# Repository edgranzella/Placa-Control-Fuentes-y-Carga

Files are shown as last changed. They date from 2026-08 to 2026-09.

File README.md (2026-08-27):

# Placa Control Fuentes y Carga - Hardware y PCB 🚀

Este repositorio contiene el diseño completo de la placa de circuito impreso (PCB) desarrollado en **KiCad 10** para el sistema de **Control de Fuentes y Gestión de Carga de Baterías**.

---

## 📌 Características del Diseño
* **Gestión de Energía:** Monitoreo y conmutación inteligente entre fuentes de alimentación principales y sistemas de respaldo por batería.
* **Etapa de Carga Integrada:** Circuito de control dedicado para la recarga segura, regulación de corriente y protección térmica del banco de baterías.
* **Supervisión Analógica:** Divisores de tensión de precisión y sensores de corriente dispuestos para la telemetría de voltajes críticos.
* **Protección de Entrada:** Fusibles rearmables, diodos de protección contra inversión de polaridad y supresores de transitorios (TVS).

---

## 🛠️ Especificaciones Técnicas de Fabricación
Configuración sugerida basada en las reglas de diseño (DRC) aplicadas en KiCad 10:

| Parámetro | Configuración Sugerida |
| :--- | :--- |
| **Capas (Layers)** | 2 Capas |
| **Grosor de la Placa** | 1.6 mm |
| **Grosor del Cobre** | 1 oz / 2 oz (Recomendado para pistas de alta corriente en etapas de carga) |
| **Acabado Superficial** | HASL (with lead) o ENIG |

---

## 👥 Desarrollado por
* **Damian Granzella** - *Ingeniería de Hardware* - [edgranzella](https://github.com)

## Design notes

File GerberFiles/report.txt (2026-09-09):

Trazado a 'C:\Users\dgranzella\Documents\Control de Fuentes y Batería\Placa Control Fuentes y Carga\GerberFiles\Placa Control Fuentes y Carga-F_Cu.gbr'.
Trazado a 'C:\Users\dgranzella\Documents\Control de Fuentes y Batería\Placa Control Fuentes y Carga\GerberFiles\Placa Control Fuentes y Carga-B_Cu.gbr'.
Trazado a 'C:\Users\dgranzella\Documents\Control de Fuentes y Batería\Placa Control Fuentes y Carga\GerberFiles\Placa Control Fuentes y Carga-F_Paste.gbr'.
Trazado a 'C:\Users\dgranzella\Documents\Control de Fuentes y Batería\Placa Control Fuentes y Carga\GerberFiles\Placa Control Fuentes y Carga-F_Silkscreen.gbr'.
Trazado a 'C:\Users\dgranzella\Documents\Control de Fuentes y Batería\Placa Control Fuentes y Carga\GerberFiles\Placa Control Fuentes y Carga-F_Mask.gbr'.
Trazado a 'C:\Users\dgranzella\Documents\Control de Fuentes y Batería\Placa Control Fuentes y Carga\GerberFiles\Placa Control Fuentes y Carga-B_Mask.gbr'.
Trazado a 'C:\Users\dgranzella\Documents\Control de Fuentes y Batería\Placa Control Fuentes y Carga\GerberFiles\Placa Control Fuentes y Carga-Edge_Cuts.gbr'.
Trazado a 'C:\Users\dgranzella\Documents\Control de Fuentes y Batería\Placa Control Fuentes y Carga\GerberFiles\Placa Control Fuentes y Carga-F_Courtyard.gbr'.
Trazado a 'C:\Users\dgranzella\Documents\Control de Fuentes y Batería\Placa Control Fuentes y Carga\GerberFiles\Placa Control Fuentes y Carga-F_Fab.gbr'.
Archivo de trabajo Gerber 'C:\Users\dgranzella\Documents\Control de Fuentes y Batería\Placa Control Fuentes y Carga\GerberFiles\Placa Control Fuentes y Carga-job.gbrjob' creado.
Info: Listo.

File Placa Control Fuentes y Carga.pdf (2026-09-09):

Referencia | Cantidad | Valor | Descripción
C1, C5 | 2 | 1nF/50V | Capacitor cerámico de desacople / filtro
C2 | 1 | 22nF/50V | Capacitor cerámico de desacople
C3, C4, C6, C8, C9, C12, C19, C20, C22, C24, C25 | 11 | 100nF/50V | Capacitor cerámico de desacople común (0.1µF)
C7, C10, C11, C16 | 4 | F102K43Y5RP6UK5R | Capacitor cerámico de alta tensión / dieléctrico Y5R
C13, C14 | 2 | 10uF/25V | Capacitor electrolítico o cerámico de filtrado
C15, C23 | 2 | 470µF/35V low-ESR | Capacitor electrolítico de baja resistencia serie para fuentes conmutadas
C17, C21 | 2 | 10µF/25V | Capacitor electrolítico de filtrado de propósito general
C18 | 1 | 100µF/25V | Capacitor electrolítico de estabilización de tensión
CR1, CR2 | 2 | SMBJ18A | Diodo supresor de picos de tensión (TVS) unidireccional de 18V (SMD)
CR3 | 1 | SMBJ16A | Diodo supresor de picos de tensión (TVS) unidireccional de 16V (SMD)
D1, D4, D6 | 3 | 1N4007 | Diodo rectificador de silicio estándar (1A / 1000V)
D2, D3, D8 | 3 | P2000M | Diodo rectificador de silicio de alta corriente (20A / 1000V)
D5 | 1 | Zener-10V | Diodo Zener de regulación de voltaje fijo (10V)
D7, D9-D11, D16 | 5 | 1N4733A | Diodo Zener de regulación de voltaje de 5.1V / 1W
D12 | 1 | SM712 | Diodo TVS dual asimétrico para protección de líneas de datos (RS-485)
D13, D14 | 2 | SA12CA | Diodo supresor de picos de tensión (TVS) bidireccional de 12V
D15 | 1 | SA6.5CA | Diodo supresor de picos de tensión (TVS) bidireccional de 6.5V
F1 | 1 | ETA 1610-H2-7.5A | Fusible automotriz de acción rápida (tipo mini / disyuntor térmico 7.5A)
F2 | 1 | Polyfuse MF-R500 | Fusible PTC reseteable (Polyswitch) de 5A / protección por sobrecorriente
F3, F4 | 2 | MF-R030 | Fusible PTC reseteable (Polyswitch) de 0.3A (300mA)
F5, F6 | 2 | ETA 1610-H2-5A | Fusible automotriz de acción rápida (tipo mini / disyuntor térmico 5A)
GD1 | 1 | 2036-15-B2LF | Tubo de descarga de gas (GDT) para protección contra sobretensiones (150V)
J1-J9 | 9 | TBP01R1-508-02BE | Bloque de terminales enchufable de 2 pines (Paso 5.08mm)
J10 | 1 | TBP01R1-508-03BE | Bloque de terminales enchufable de 3 pines (Paso 5.08mm)
J11 | 1 | 4P-2.54mm-SHROUDED-VERT | CONN HEADER VERT 4POS 2.54MM SHROUDED THT
JP1-JP4 | 4 | Jumper_2_Open | Puntos de selección mediante Jumper (2 pines, normalmente abiertos)
Q1 | 1 | IRF9540NPbF | Transistor MOSFET de potencia Canal P (-100V, -23A, 117mΩ, 140W, TO-220AB)
Q2 | 1 | 2N3904 | Transistor bipolar BJT de tipo NPN de propósito general / conmutación de baja señal
Q3, Q4 | 2 | BC558 | Transistor bipolar BJT de tipo PNP de bajo ruido y baja señal
Q5 | 1 | IRF5305 | Transistor de potencia MOSFET de Canal P (-55V / -31A)
Q6 | 1 | BC337 | Transistor bipolar BJT de tipo NPN de mediana potencia / corriente (hasta 800mA)
Q7 | 1 | BC327 | Transistor bipolar BJT de tipo PNP de mediana potencia / corriente (hasta 800mA)
R1, R2, R5 | 3 | 150K 1/4W | Resistencia fija de película de carbón/metal de 150 kΩ
R3, R4 | 2 | 56K 0.5W | Resistencia fija de 56 kΩ con disipación de media potencia (0.5 vatios)
R6, R9, R14, R16 | 4 | 10K 1/4W | Resistencia fija de precisión / pull-up estándar de 10 kΩ

Lista de Materiales Placa Controladora de Fuentes y Carga V2

R7 | 1 | 56K 1/4W | Resistencia fija de propósito general de 56 kΩ
R8 | 1 | 3K3 1/4W | Resistencia fija de propósito general de 3.3 kΩ
R10-R12 | 3 | 18K 1/4W | Resistencia fija de propósito general de 18 kΩ
R13, R15 | 2 | 1K 1/4W | Resistencia fija de control / limitación de corriente de 1 kΩ
R17 | 1 | 470 1/4W | Resistencia fija de limitación de corriente de 470 Ω
R18, R19 | 2 | 560 1/4W | Resistencia fija de limitación de corriente de 560 Ω
R20 | 1 | 120 1/4W | Resistencia de terminación de bus de comunicación de 120 Ω
R21, R26 | 2 | 1M 1/4W | Resistencia fija de alta impedancia de 1 MΩ
R22, R23 | 2 | 47 1/4W | Resistencia de amortiguación o protección de baja impedancia de 47 Ω
R24, R25 | 2 | B72214S0271K101 | Varistor de óxido metálico (MOV) de 270V para absorción de transitorios transitorios
RV1-RV3 | 3 | 50K | Potenciómetro / Resistencia variable ajustable de 50 kΩ
TP1-TP12, TP14-TP26 | 25 | TestPoint | Puntos físicos de prueba en el circuito impreso para multímetro/osciloscopio
U1, U6 | 2 | ACS724LLCTR-05AB-T | Sensor de corriente de efecto Hall integrado (aislado, rango ±5A)
U2 | 1 | Relay_Module_WB-083 | Módulo de relé electromecánico para control de cargas de potencia
U3 | 1 | 4N35 | Optoacoplador con salida a fototransistor (aislamiento galvánico de señales)
U4 | 1 | LM2596S_Modulo_Regulable | Módulo regulador de voltaje conmutado Step-Down (reductor DC-DC)
U5 | 1 | Arduino_Nano_ATmega328P | Módulo microcontrolador de desarrollo basado en el chip ATmega328P
U7 | 1 | MAX485E | Circuito integrado transceptor para comunicaciones industriales RS-485 / RS-422
U8 | 1 | MAX22445FAWE+ | Aislador digital galvánico reforzado de alta velocidad y 4 canales
U9 | 1 | RI3-0505S | Convertidor DC-DC aislado de tipo industrial (entrada 5V / salida 5V regulada)

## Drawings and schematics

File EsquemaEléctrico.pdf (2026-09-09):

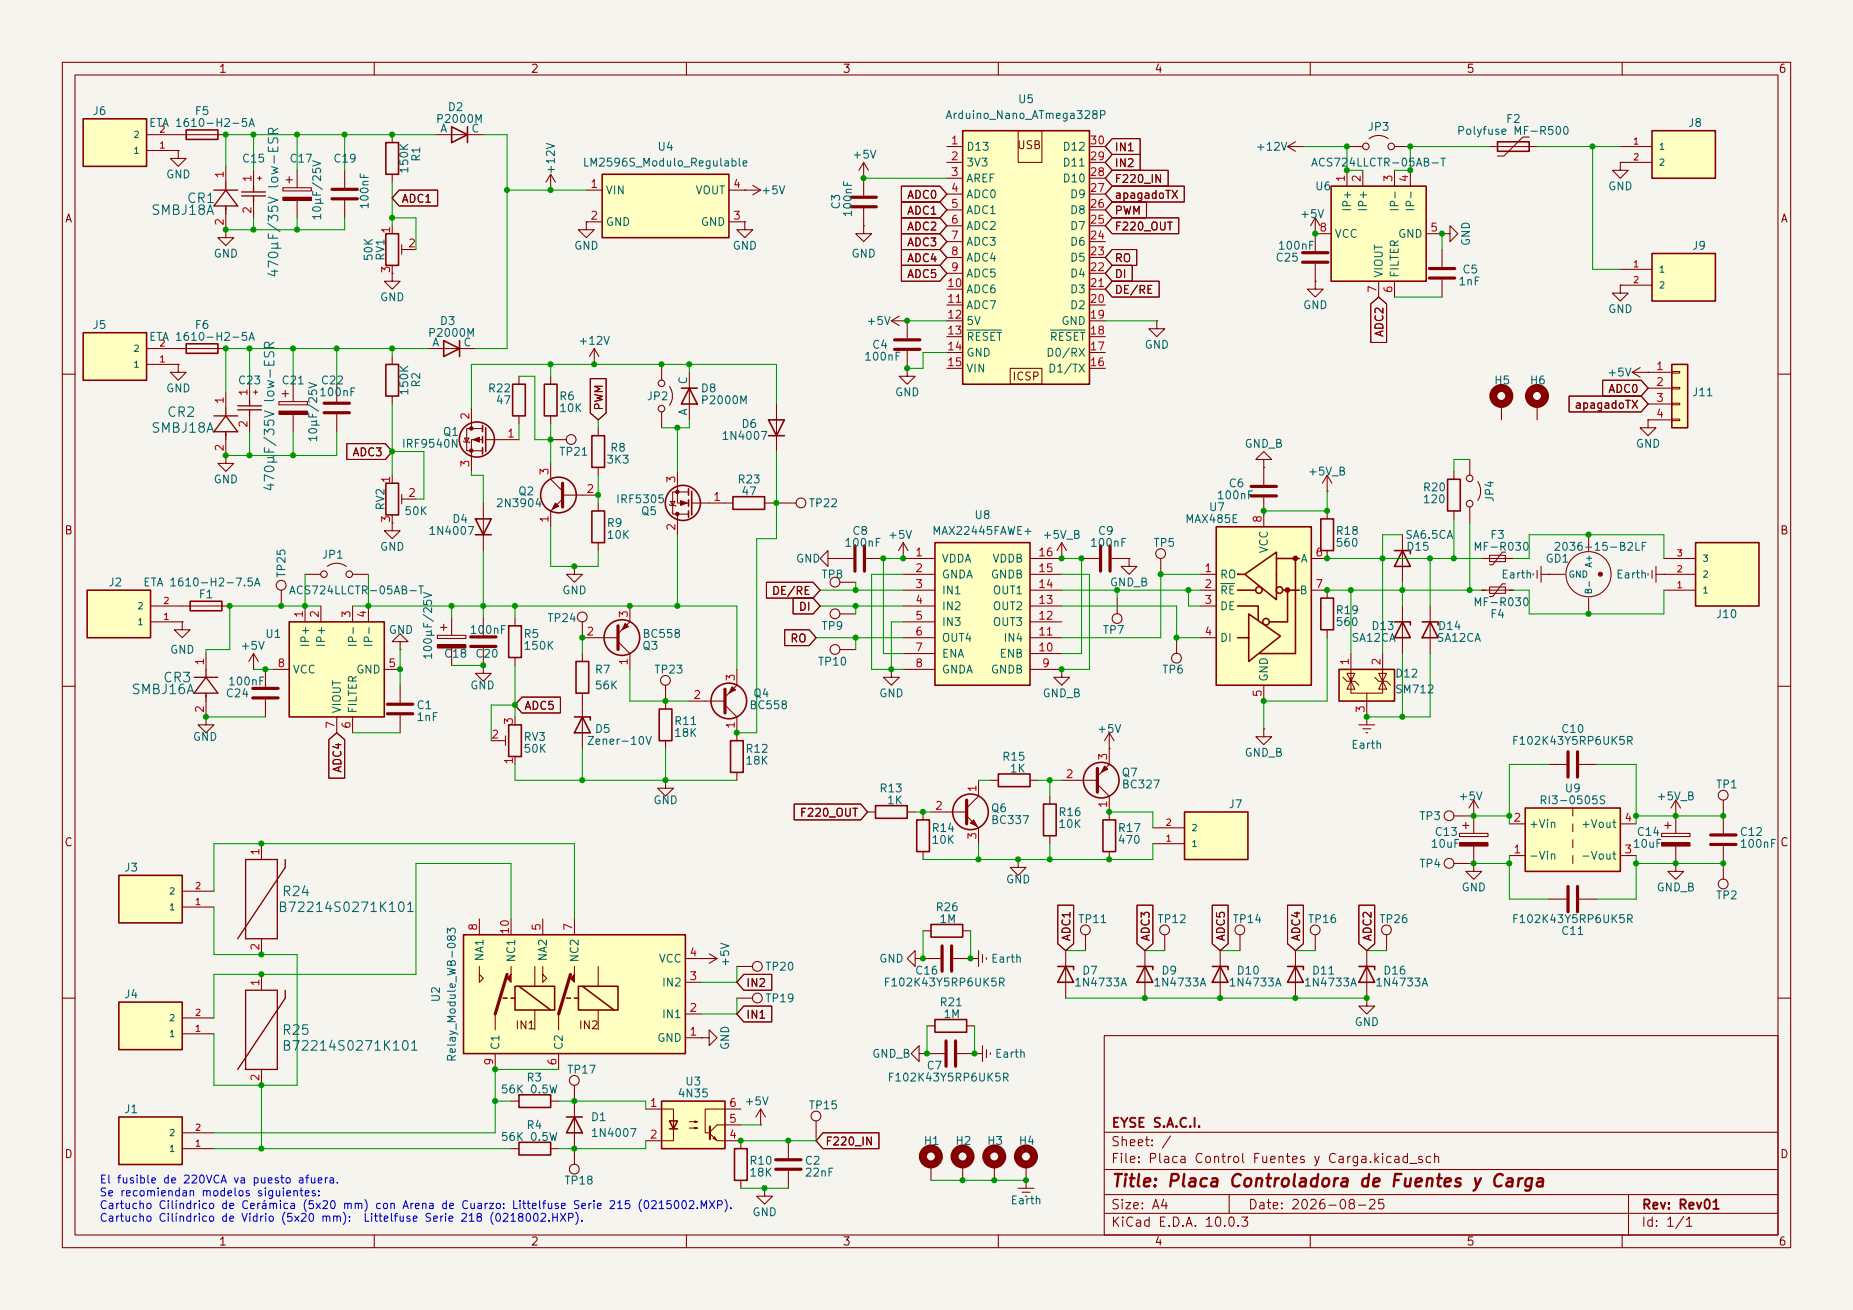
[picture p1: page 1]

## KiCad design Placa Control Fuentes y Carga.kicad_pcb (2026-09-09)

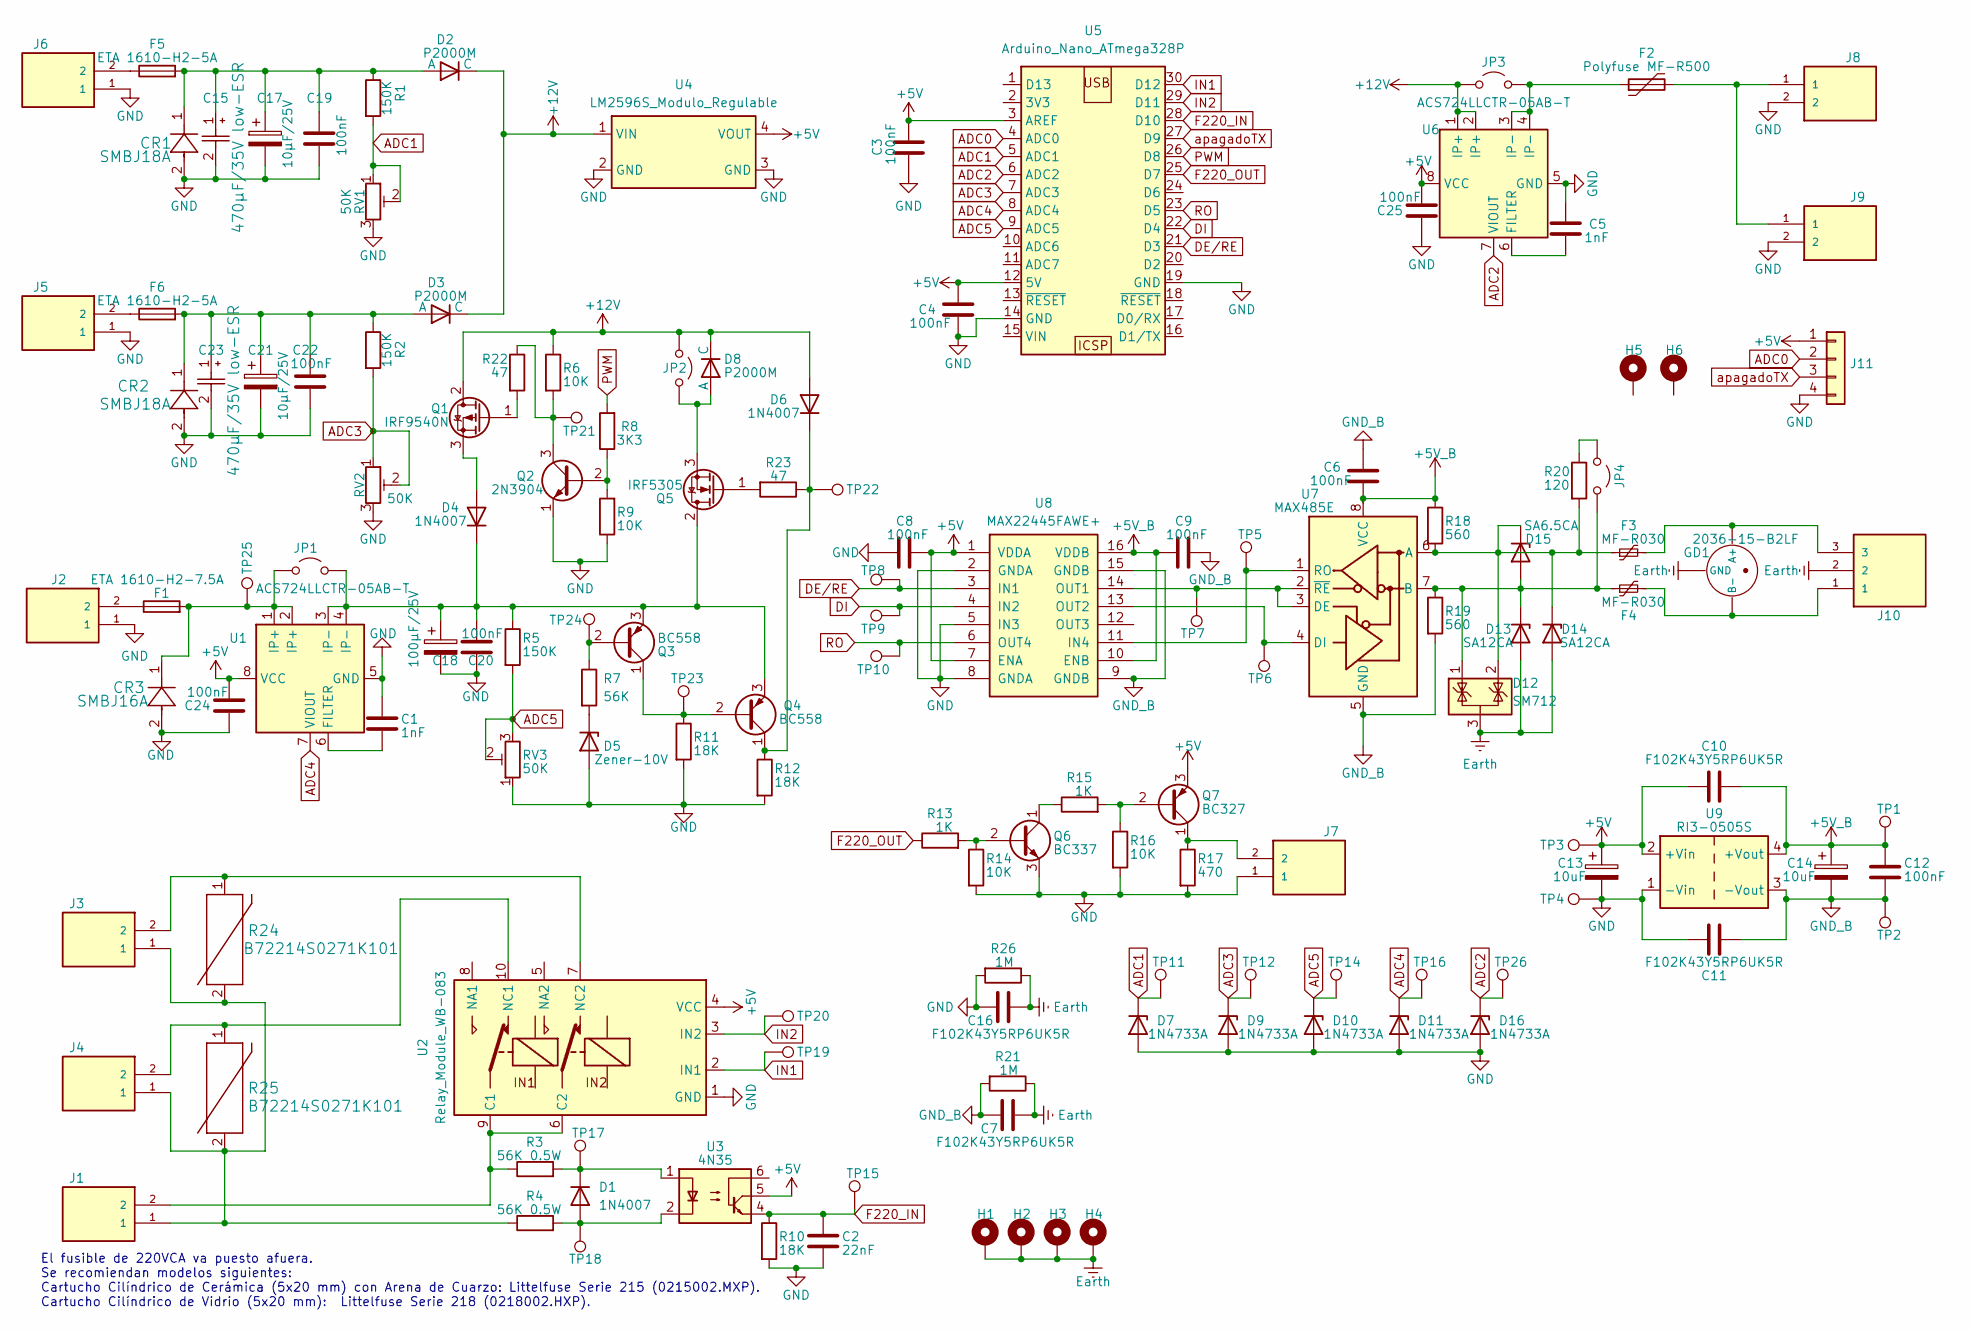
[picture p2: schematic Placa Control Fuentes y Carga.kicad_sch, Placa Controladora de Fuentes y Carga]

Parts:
C1, C5: 1nF; C_Disc_D5.0mm_W2.5mm_P2.50mm
C2: 22nF; C_Disc_D5.0mm_W2.5mm_P2.50mm
C3, C4, C6, C8, C9, C12, C19, C20, C22, C24, C25: 100nF; C_Disc_D5.0mm_W2.5mm_P2.50mm
C7, C10, C11, C16: F102K43Y5RP6UK5R; CAP_F_11X5P_VIS
C13, C14: 10uF; CP_Radial_D5.0mm_P2.00mm
C15, C23: 470µF/35V low-ESR; CAP_UAQ_10X20_NCH
C17, C21: 10µF/25V; CP_Radial_D5.0mm_P2.00mm
C18: 100µF/25V; CP_Radial_D5.0mm_P2.00mm
CR1, CR2: SMBJ18A; DIODE_DO214AA
CR3: SMBJ16A; DIODE_DO214AA
D1, D4, D6: 1N4007; D_DO-41_SOD81_P10.16mm_Horizontal
D2, D3, D8: P2000M; D_P600_R-6_P15.24mm_Horizontal
D5: Zener-10V; D_DO-35_SOD27_P7.62mm_Horizontal
D7, D9, D10, D11, D16: 1N4733A; D_DO-41_SOD81_P10.16mm_Horizontal
D12: SM712; SOT-23_Handsoldering
D13, D14: SA12CA; DO-204AC_SA
D15: SA6.5CA; DO-204AC_SA
F1: ETA 1610-H2-7.5A; FuseHolder_Blade_ATO_Littelfuse_FLR_178.6165
F2: Polyfuse MF-R500; FUSE_MF-R500_BRN
F3, F4: MF-R030; Fuse_Bourns_MF-RHT050
F5, F6: ETA 1610-H2-5A; FuseHolder_Blade_ATO_Littelfuse_FLR_178.6165
GD1: 2036-15-B2LF; GDT_Yageo_3RxxxxL-6
H1, H2, H3, H4, H5, H6: MountingHole_Pad; MountingHole_3.2mm_M3_Pad
J1, J2, J3, J4, J5, J6, J7, J8, J9: TBP01R1-508-02BE; TerminalBlock_Phoenix_MKDS-1,5-2-5.08_1x02_P5.08mm_Horizont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
J10: TBP01R1-508-03BE; TerminalBlock_Phoenix_MKDS-1,5-2-5.08_1x03_P5.08mm_Horizont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
J11: Conn_01x04; PinHeader_1x04_P2.54mm_Vertical
JP1, JP2, JP3, JP4: Jumper_2_Open; PinHeader_1x02_P2.54mm_Vertical
Q1: IRF9540N; TO-220-3_Vertical
Q2: 2N3904; TO-92_Inline
Q3, Q4: BC558; TO-92_HandSolder
Q5: IRF5305; TO-220-3_Vertical
Q6: BC337; TO-92_HandSolder
Q7: BC327; TO-92_HandSolder
R1, R2, R5: 150K; R_Axial_DIN0207_L6.3mm_D2.5mm_P7.62mm_Horizontal
R3, R4: 56K 0.5W; R_Axial_DIN0309_L9.0mm_D3.2mm_P12.70mm_Horizontal
R6, R9, R14, R16: 10K; R_Axial_DIN0207_L6.3mm_D2.5mm_P7.62mm_Horizontal
R7: 56K; R_Axial_DIN0207_L6.3mm_D2.5mm_P7.62mm_Horizontal
R8: 3K3; R_Axial_DIN0207_L6.3mm_D2.5mm_P7.62mm_Horizontal
R10, R11, R12: 18K; R_Axial_DIN0207_L6.3mm_D2.5mm_P7.62mm_Horizontal
R13, R15: 1K; R_Axial_DIN0207_L6.3mm_D2.5mm_P7.62mm_Horizontal
R17: 470; R_Axial_DIN0207_L6.3mm_D2.5mm_P7.62mm_Horizontal
R18, R19: 560; R_Axial_DIN0207_L6.3mm_D2.5mm_P7.62mm_Horizontal
R20: 120; R_Axial_DIN0207_L6.3mm_D2.5mm_P7.62mm_Horizontal
R21, R26: 1M; R_Axial_DIN0207_L6.3mm_D2.5mm_P7.62mm_Horizontal
R22, R23: 47; R_Axial_DIN0207_L6.3mm_D2.5mm_P7.62mm_Horizontal
R24, R25: B72214S0271K101; VARS_B72214S0271K101_TDK
RV1, RV2, RV3: 50K; Potentiometer_Bourns_3296W_Vertical
TP1, TP2, TP3, TP4, TP5, TP6, TP7, TP8, TP9, TP10, TP11, TP12, TP14, TP15, TP16, TP17, TP18, TP19, TP20, TP21, TP22, TP23, TP24, TP25, TP26: TestPoint; TestPoint_THTPad_D2.5mm_Drill1.2mm
U1, U6: ACS724LLCTR-05AB-T; SOIC-8_3.9x4.9mm_P1.27mm
U2: Relay_Module_WB-083
U3: 4N35; DIP-6_W7.62mm
U4: LM2596S_Modulo_Regulable; Modulo Step Down Regulable LM2596
U5: Arduino_Nano_ATmega328P; Arduino_Nano
U7: MAX485E; SOIC-8_3.9x4.9mm_P1.27mm
U8: MAX22445FAWE+; SOIC-16W_7.5x10.3mm_P1.27mm
U9: RI3-0505S; CONV_RI3-0505S

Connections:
+5V: C3.1, C4.1, C8.1, C10.2, C13.1, C24.2, C25.2, J11.1, Q7.3 (E), TP3.1 (1_1), U1.8 (VCC), U2.4 (VCC), U3.5, U4.4 (VOUT), U5.3 (AREF), U5.12 (5V), U6.8 (VCC), U8.1 (VDDA), U8.7 (ENA), U9.2 (+Vin)
+5V_B: C6.2, C9.2, C10.1, C12.1, C14.1, R18.1, TP1.1 (1_1), U7.8 (VCC), U8.10 (ENB), U8.16 (VDDB), U9.4 (+Vout)
+12V: D2.1 (C), D3.1 (C), D6.2 (A), D8.1 (C), JP2.1 (A), JP3.1 (A), Q1.2 (D), R6.1, U4.1 (VIN), U6.1 (IP+), U6.2 (IP+)
ADC0: J11.2, U5.4 (ADC0)
ADC1: D7.1 (K), R1.2, RV1.1, RV1.2, TP11.1 (1_1), U5.5 (ADC1)
ADC2: D16.1 (K), TP26.1 (1_1), U5.6 (ADC2), U6.7 (VIOUT)
ADC3: D9.1 (K), R2.2, RV2.1, RV2.2, TP12.1 (1_1), U5.7 (ADC3)
ADC4: D11.1 (K), TP16.1 (1_1), U1.7 (VIOUT), U5.8 (ADC4)
ADC5: D10.1 (K), R5.2, RV3.2, RV3.3, TP14.1 (1_1), U5.9 (ADC5)
DE/RE: TP8.1 (1_1), U5.21 (D3), U8.3 (IN1)
DI: TP9.1 (1_1), U5.22 (D4), U8.4 (IN2)
Earth: C7.2, C16.2, D12.3 (A), D13.2 (A), D14.2 (A), GD1.2 (GND), H1.1 (1_1), H2.1 (1_1), H3.1 (1_1), H4.1 (1_1), J10.2, R21.1, R26.1
F220_IN: C2.1, R10.1, TP15.1 (1_1), U3.4, U5.28 (D10)
F220_OUT: R13.1, U5.25 (D7)
GND: C1.1, C2.2, C3.2, C4.2, C5.1, C8.2, C11.2, C13.2, C15.2, C16.1, C17.2, C18.2, C19.2, C20.1, C21.2, C22.1, C23.2, C24.1, C25.1, CR1.2, CR2.2, CR3.2, D5.2 (A), D7.2 (A), D9.2 (A), D10.2 (A), D11.2 (A), D16.2 (A), J2.1, J5.1, J6.1, J7.1, J8.2, J9.2, J11.4, Q2.1 (E), Q6.3 (E), R9.1, R10.2, R11.2, R12.2, R14.2, R16.2, R17.2, R26.2, RV1.3, RV2.3, RV3.1, TP4.1 (1_1), U1.5 (GND), U2.1 (GND), U4.2 (GND), U4.3 (GND), U5.14 (GND), U5.19 (GND), U6.5 (GND), U8.2 (GNDA), U8.5 (IN3), U8.8 (GNDA), U9.1 (-Vin)
GND_B: C6.1, C7.1, C9.1, C11.1, C12.2, C14.2, R19.2, R21.2, TP2.1 (1_1), U7.5 (GND), U8.9 (GNDB), U8.15 (GNDB), U9.3 (-Vout)
IN1: TP19.1 (1_1), U2.2 (IN1), U5.30 (D12)
IN2: TP20.1 (1_1), U2.3 (IN2), U5.29 (D11)
unnamed: D1.2 (A), R4.2, TP18.1 (1_1), U3.2
unnamed: D1.1 (K), R3.2, TP17.1 (1_1), U3.1
unnamed: C15.1, C17.1, C19.1, CR1.1, D2.2 (A), F5.2, R1.1
unnamed: C21.1, C22.2, C23.1, CR2.1, D3.2 (A), F6.2, R2.1
unnamed: D4.2 (A), Q1.3 (S)
unnamed: C18.1, C20.2, D4.1 (K), JP1.2 (B), Q3.3 (E), Q4.3 (E), Q5.2 (D), R5.1, U1.3 (IP-), U1.4 (IP-)
unnamed: D5.1 (K), R7.2
unnamed: D6.1 (K), Q4.1 (C), R12.1, R23.1, TP22.1 (1_1)
unnamed: D8.2 (A), JP2.2 (B), Q5.3 (S)
unnamed: D12.1 (K), D13.1 (K), D15.2 (A), F4.1, JP4.2 (B), R19.1, U7.7 (B)
unnamed: D12.2 (K), D14.1 (K), D15.1 (K), F3.1, R18.2, R20.2, U7.6 (A)
unnamed: F1.1, J2.2
unnamed: F2.2, J8.1, J9.1
unnamed: F5.1, J6.2
unnamed: F6.1, J5.2
unnamed: F3.2, GD1.1 (A+), J10.3
unnamed: F4.2, GD1.3 (B-), J10.1
unnamed: J1.1, J3.1, J4.1, R4.1, R24.2, R25.2
unnamed: CR3.1, F1.2, JP1.1 (A), TP25.1 (1_1), U1.1 (IP+), U1.2 (IP+)
unnamed: F2.1, JP3.2 (B), U6.3 (IP-), U6.4 (IP-)
unnamed: JP4.1 (A), R20.1
unnamed: Q1.1 (G), R22.2
unnamed: Q2.2 (B), R8.1, R9.2
unnamed: Q2.3 (C), R6.2, R22.1, TP21.1 (1_1)
unnamed: Q3.2 (B), R7.1, TP24.1 (1_1)
unnamed: Q3.1 (C), Q4.2 (B), R11.1, TP23.1 (1_1)
unnamed: Q5.1 (G), R23.2
unnamed: Q6.2 (B), R13.2, R14.1
unnamed: Q6.1 (C), R15.1
unnamed: Q7.2 (B), R15.2, R16.1
unnamed: J7.2, Q7.1 (C), R17.1
unnamed: C1.2, U1.6 (FILTER)
unnamed: J1.2, R3.1, U2.6 (C2), U2.9 (C1)
unnamed: J4.2, R25.1, U2.10 (NC1)
unnamed: J3.2, R24.1, U2.7 (NC2)
unnamed: C5.2, U6.6 (FILTER)
unnamed: TP7.1 (1_1), U7.2 (~RE), U7.3 (DE), U8.14 (OUT1)
unnamed: TP6.1 (1_1), U7.4 (DI), U8.13 (OUT2)
unnamed: TP5.1 (1_1), U7.1 (RO), U8.11 (IN4)
PWM: R8.2, U5.26 (D8)
RO: TP10.1 (1_1), U5.23 (D5), U8.6 (OUT4)
apagadoTX: J11.3, U5.27 (D9)

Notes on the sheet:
El fusible de 220VCA va puesto afuera. Se recomiendan modelos siguientes: Cartucho Cilíndrico de Cerámica (5x20 mm) con Arena de Cuarzo: Littelfuse Serie 215 (0215002.MXP). Cartucho Cilíndrico de Vidrio (5x20 mm): Littelfuse Serie 218 (0218002.HXP).

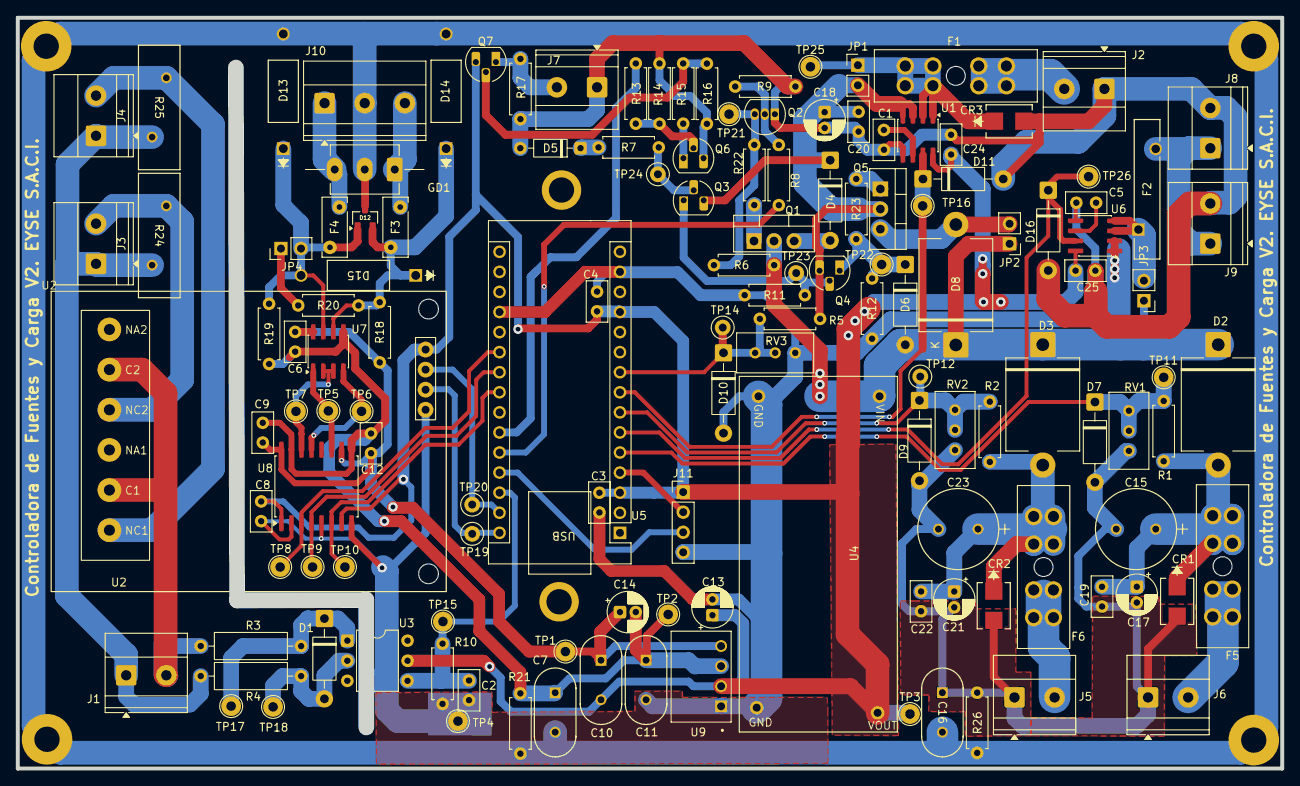
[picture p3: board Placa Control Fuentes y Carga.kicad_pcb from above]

Board: 2 copper layers, 160.0 x 95.0 mm, 142 parts (0 on the bottom side), 60 nets.

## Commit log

2026-08-27 Hardware: Estructura inicial limpia de control de fuentes en KiCad 10
    [PCB_Placa-control-con-pi_2026-08-25.pcbdoc, Placa Control Fuentes y Carga.kicad_pcb, Placa Control Fuentes y Carga.kicad_sch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]
2026-08-27 Siguen las actualizaciones. Siguiente paso: Faltan asociar footprints a muchos símbolos. Tengo que ver la asignaciones hechas en los proyectos anteriores, listarlos y con esa información podré comple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
    [Placa Control Fuentes y Carga.kicad_sch, Placa_Control_Fuentes_y_Carga_v1.kicad_sch]
2026-08-28 Hacemos backup por las dudas de las pequeñas modificaciones realizadas. Lo que sigue es hacer toda la interface RS485 aislada, protegida, igual que con la placa expansora de ocho relés.
    [Placa Control Fuentes y Carga.kicad_sch]
2026-08-31 Ya se completaron diria el total de los footprints para cada símbolo. Falta hacer una revisión general más detallada y luego pasar al PCB directo.
    [Placa Control Fuentes y Carga.kicad_sch]
2026-08-31 Más actualizaciones en el sch antes de pasar al PCB.
    [Placa Control Fuentes y Carga.kicad_sch]
2026-09-01 Se hicieron muchas correcciones en el circuito y en los footprints del PCB. Esto es solo para guardar un respaldo.
    [Placa Control Fuentes y Carga.kicad_pcb, Placa Control Fuentes y Carga.kicad_sch]
2026-09-03 feat(pcb): placement inicial y netlist vinculada en placa 2 capas
    - Placa 2 capas FR4 1.6 mm; contorno Edge.Cuts ~160 x 95 mm
    - 142 footprints colocados (cara top); netlist asociada a pads
    - Dominios de tierra en netlist: GND (principal) y GND_B (RS-485 aislado)
    - Secciones ubicadas: entrada/OR-ing, LM2596, sensado ACS724, rele,
    RS-485 (MAX485E/MAX22445/RI3-0505S) y deteccion 220 VCA (4N35/GDT)
    Pendiente (no incluido en este commit):
    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
    [Placa Control Fuentes y Carga.kicad_pcb, Placa Control Fuentes y Carga.kicad_sch]
2026-09-04 feat(pcb): ruteo parcial + planos GND/+12V y keepouts de aislamiento
    Estado actual:
    - Placa 2 capas FR4 1.6 mm, contorno ~160 x 95 mm, 141 footprints
    - Ruteo parcial: 400 segmentos (138 F.Cu / 262 B.Cu) + 6 vias
    - Planos rellenados (locked): GND x4 (masa1-4, F.Cu/B.Cu, prio 1-3)
    y +12V (12V_1, B.Cu)
    - 9 keepouts en F.Cu para barreras de aislamiento
    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
    [Placa Control Fuentes y Carga.kicad_pcb]
2026-09-04 En relación a la versión anterior, comenzamos a acomodar las conexiones de batería.
    [Placa Control Fuentes y Carga.kicad_pcb]
2026-09-07 feat(pcb): ruteo casi completo + planos GND/+5V/+12V y earth ancho
    == Avances mas notables ==
    - Ruteo: 682 segmentos (242 F.Cu / 440 B.Cu) + 19 vias
    - 57/76 nets ruteadas; solo faltan 2 senales reales: ADC0 y PWM
    (el resto de "unconnected" son pads NC de U5/U2/U3/U8)
    - Planos rellenados (locked): GND x4 (masa1-4, F.Cu+B.Cu),
    +5V (cincoV1, F.Cu) y +12V (B.Cu)
    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
    [Placa Control Fuentes y Carga.kicad_pcb, Placa Control Fuentes y Carga.kicad_sch]
2026-09-07 wip(pcb): ruteo 58/76 (falta ADC0); GND_B sin plano; barrera 220VCA e IPC pendientes.
    feat(pcb): ruteo casi cerrado (solo falta ADC0) + refuerzo de vias
    - Ruteo: 858 segmentos (340 F.Cu / 518 B.Cu) + 33 vias (+14 vs commit previo)
    - 58/76 nets ruteadas; PWM ya ruteado -> unica senal real pendiente: ADC0
    - GND densificado (182 seg); +5V (87 seg) completado
    - Dominio aislado RS-485 cableado: GND_B (45 seg) y +5V_B (29 seg)
    - Earth de proteccion ancho (3-5 mm, 22 seg)
    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
    [Placa Control Fuentes y Carga-B_Courtyard.gbr, Placa Control Fuentes y Carga-B_Cu.gbr, Placa Control Fuentes y Carga-B_Fab.gbr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]
2026-09-08 Se hicieron los gerbers y drill files.
    [Placa Control Fuentes y Carga-B_Courtyard.gbr, Placa Control Fuentes y Carga-B_Cu.gbr, Placa Control Fuentes y Carga-B_Fab.gbr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]
2026-09-08 Se hicieron mínimas correcciones en la parte de la serigrafía y para que los gerbers files vayan en consonancia con los requisitos estéticos de la placa.
    [Placa Control Fuentes y Carga-B_Courtyard.gbr, Placa Control Fuentes y Carga-B_Cu.gbr, Placa Control Fuentes y Carga-B_Fab.gbr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]
2026-09-09 Se le agregó el conector con las señales de +5V, GND, ADC0 y apagadoTX para la plaqueita adicional de corte de TX que irá apilada encima con dos tornillos de 1/8 para sujeción mecánica arriba del ard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
    [Placa Control Fuentes y Carga-B_Cu.gbr, Placa Control Fuentes y Carga-B_Mask.gbr, Placa Control Fuentes y Carga-Edge_Cuts.gbr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]
2026-09-09 Actualización de lista de materiales y pdfs con circuito eléctrico.
    [Lista de Materiales Placa Control Fuentes y Carga.xlsx]
